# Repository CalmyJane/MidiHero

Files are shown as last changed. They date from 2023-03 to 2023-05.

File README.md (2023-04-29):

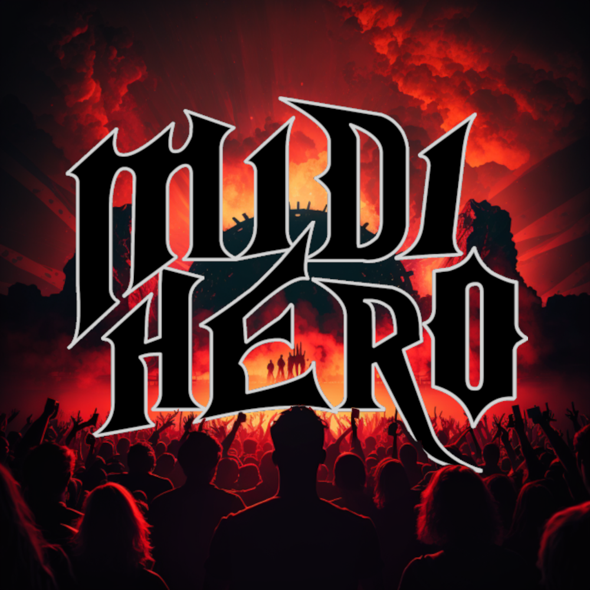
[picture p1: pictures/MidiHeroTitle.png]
Epic midi hero AI background intro image.


# 🎸 MidiHero
Transform your GuitarHero controller into a rockin' 5-pin MIDI controller for synths, man!
Btw, this readme was written by chatGPT in a "cool and authentic musician-to-musician-style" - enjoy!

## 🎶 Overview
This groovy repo provides the Arduino code and docs you need to turn a 5-button, PS3 GuitarHero controller into a rad MIDI controller. The modded axe sends MIDI notes through a 5-pin MIDI output, making it jam with any standard synth.

## 🤘 Usage Instructions
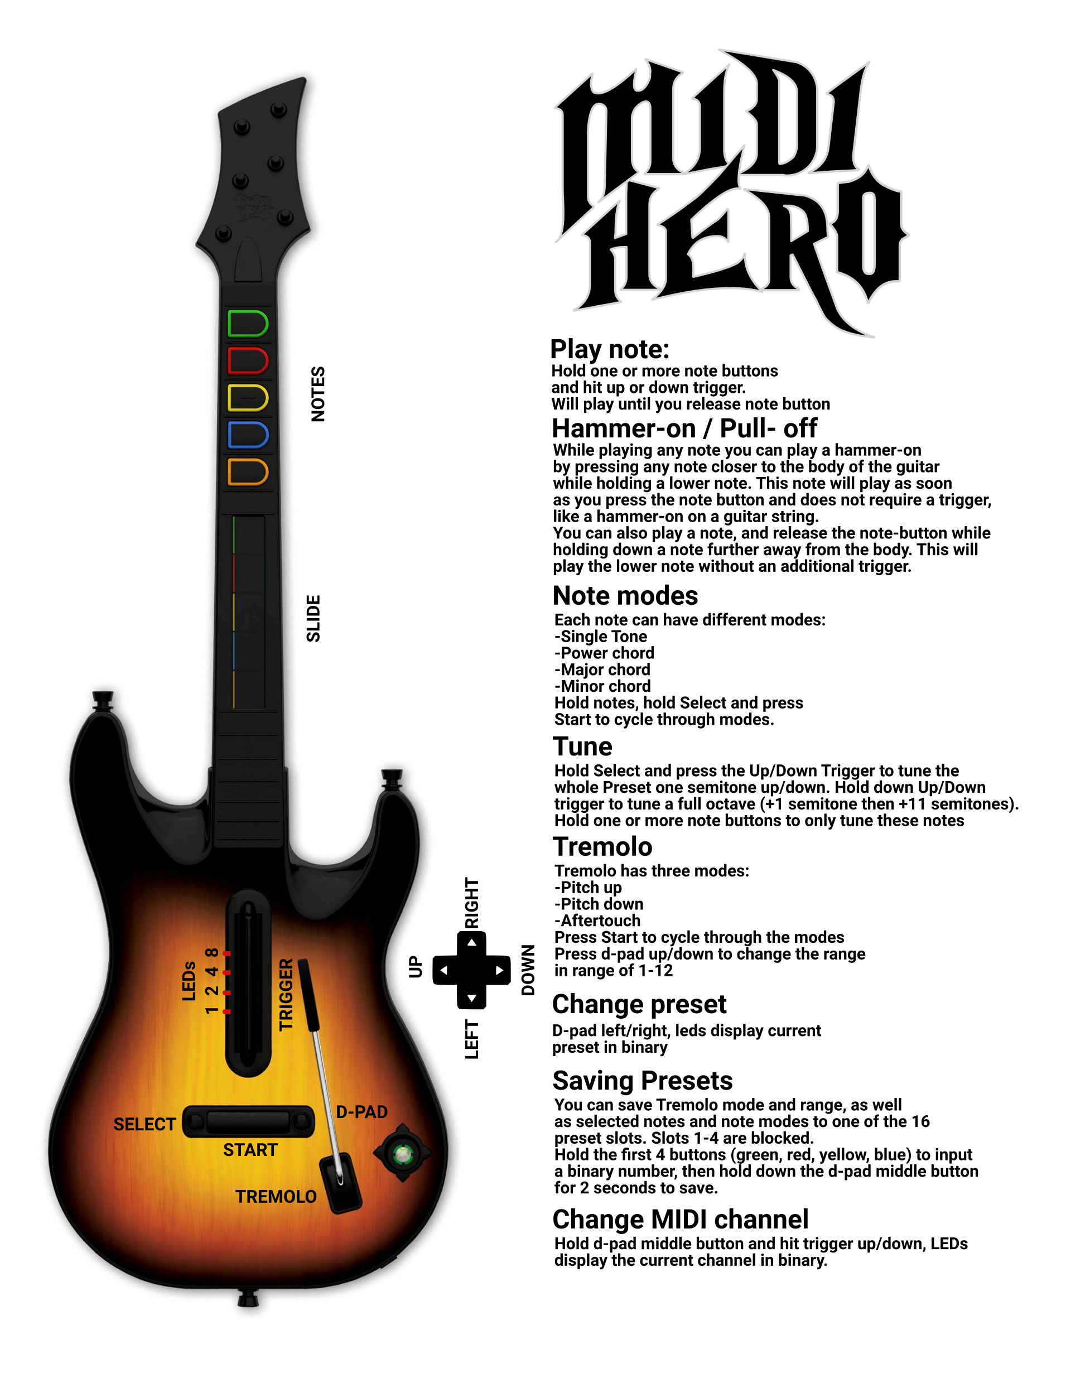
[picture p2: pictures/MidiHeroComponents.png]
Overview of the Midi Hero Guitar and it's Controls.


### Playing Notes
To shred a note, press and hold one or more `note` buttons and hit that up/down `trigger`. The note will sustain as long as you hold the `note` button, just like a real guitar, bro! Strum the `trigger` in both directions to play some wicked fast licks.

### Hammer-On / Pull-Off
While playing any note you can play a hammer-on by pressing any note closer to the body of the guitar while holding a lower note. This note will play as soon as you press the note button and does not require a trigger. You can also play a note, and release the note-button while holding down a note further away from the body. This will play the lower note without an additional trigger.

You can enable/disable hammeron functionality for any preset by holding `Select` and pressing `Start`.

### Preset Selection
Your guitar comes preloaded with 16 presets. A preset contains the currently selected notes and their modes, the current tremolo mode and tremolo range and a hammeron-flag. The LEDs indicate which is selected in binary. Press `d-pad left/right` to change the currently selected preset. Changes you make to a preset will remain until you reboot the guitar, unless you save your preset to permanently keep it on the instrument.

### Tremolo Functionality
Rock that `tremolo`! By default, it'll bend your pitch down by one semitone at full extension. You can adjust the bend range from 1 to 12 semitones! To change the range, press the `D-pad up/down`. Navigate the modes and watch for a flash of all `LEDs` to know you've made the switch. If no flash, you've hit the end of the range (1 or 12) - just navigate the other way, man!

Tremolo modes include:
* **Pitch Down** - Pitch bends down all notes by 1..12 semitones
* **Pitch Up** - Pitch bends up all notes by 1..12 semitones
* **Aftertouch** - Sends aftertouch (velocity) messages to modify current notes. With a synth like the Arturia MicroFreak, you can control anything through the modulation matrix - let your creativity flow!

You can change mode for your current preset by pressing `Start`.

### Guitar Tuning
Wanna tweak your presets? No problem, dude! Select a preset, then press and hold the `notes` you want to change. Adjust the pitch with `Shift + trigger up/down` for a semitone up or down. Transpose an entire preset by holding all notes and pressing `Shift + trigger up/down`. Just remember, custom presets won't be saved when you restart the guitar - they'll go back to default if not saved. But hey, it's a great way to reset if things get to funky!
You can also hold the up/down trigger while tuning to jump a full octave.

### Note Modes
Each note can have different modes:
* **Single Tone**
* **Power chord**
* **Major chord**
* **Minor chord**
Hold the notes you want to change, hold Select and press Start to cycle through their modes.

### MIDI Channel Selection
By default, your guitar sends notes on MIDI channel 1. We recommend setting your synth to accept all MIDI notes - check the settings! But if you need a specific channel, press the `D-pad` down and use the `up/down trigger` to change the channel. The active channel is shown in binary with flashing LEDs, from Channel 1 (1000) to Channel 15 (1111), and Channel 16 (0000). The channel is stored when device is powered off.

### Saving Presets
You can save Tremolo mode and range, as well as selected notes and note modes to one of the 16 preset slots. Hold the first 4 buttons (green, red, yellow, blue) to input a binary number, then hold the d-pad middle button to save. LEDs will blink when saved and go back to displaying the preset. Slots 1-4 are blocked and cannot be overwritten.

## Schematics

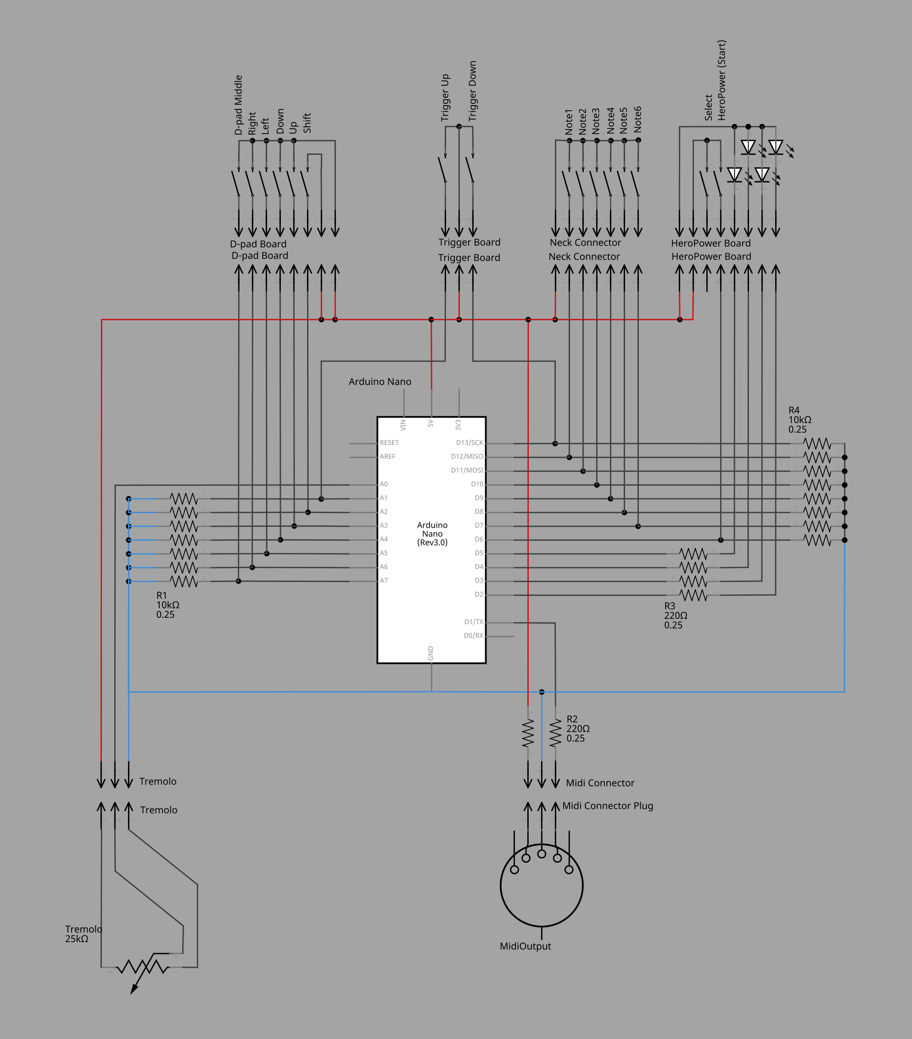
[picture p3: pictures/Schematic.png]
Schematic of the arduino and its IOs


## Internals
Inside view of the modded guitar controller
Inside the controller there is mostly Buttons that are placed on different boards. The neck is detachable and only contains the 6 `note` buttons and no additional circuitry, so it does not need to be opened or modified. Besides the buttons there is a potentiometer for the `tremolo`. Everything is attached to a controller through many flat ribbon cables. The controller is a bluetooth controller and could be used to turn something else into a guitarhero controller, maybe playing guitarhero with fruits? ;)

Inside the main frame there are 4 boards that contain several buttons. The boards usually have a GND-pin and several pins that can be connected to GND by pressing a button. To read the buttons with an arduino 5V is supplied to GND (don't get confused) of the board. The resulting signal is then read through a digital input pin with another grounding resistor. The circuit is as described in this tutorial:

https://docs.arduino.cc/built-in-examples/digital/Button

Details about the different boards inside the controller:
See the pictures folder for images of other controllers.

### Neck Connector
Some pins are not used in my version of the controller, maybe there are other controllers with an additional uController inside the neck, for now only the button-pins are used.

Front view of Neck Connector BoardBack view of Neck Connector Board

Pinout:
* 1 - Vcc - not connected
* 2 - SWDCLK - not connected
* 3 - RST/SWDIO - not connected
* 4 - MODE - not connected
* 5 - W1 - note 1
* 6 - W2 - note 2
* 7 - W3 - note 3
* 8 - B1 - note 1
* 9 - B2 - note 2
* 10- B3 - note 3
* 11- GND

### Trigger Board

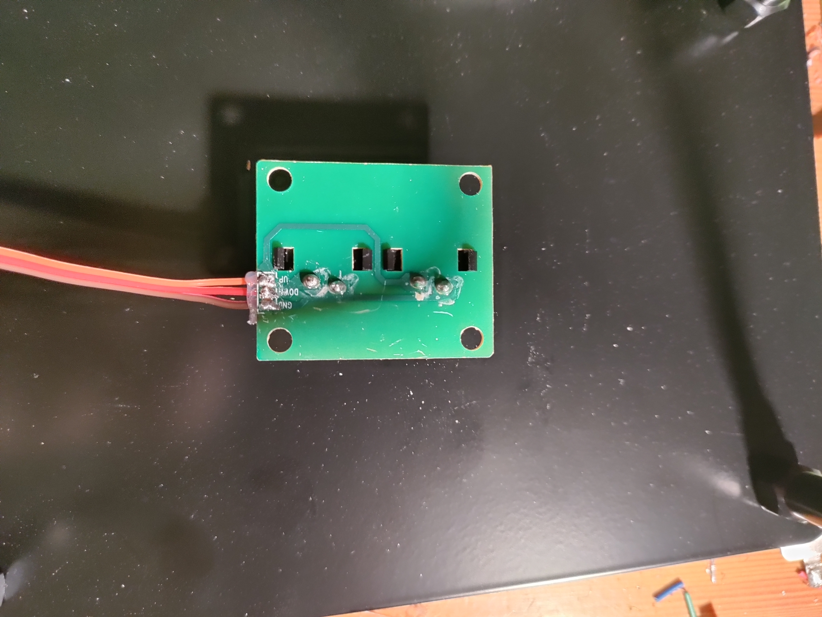
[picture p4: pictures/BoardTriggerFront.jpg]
Front view of Trigger Board
Back view of Trigger Board

Pinout:
* 1 - GND
* 2 - DOWN
* 3 - UP

### HeroPower Board
Start is the signal for the big HeroPower button, select is the two small buttons beside it. The buttons cannot be read seperately and they are not used for this mod. The board also contains 4 leds that are supplied through Vcc. They can be directly connected to the arduino (sinking their current into a digital output pin) through a 220 Ohn Resistor.

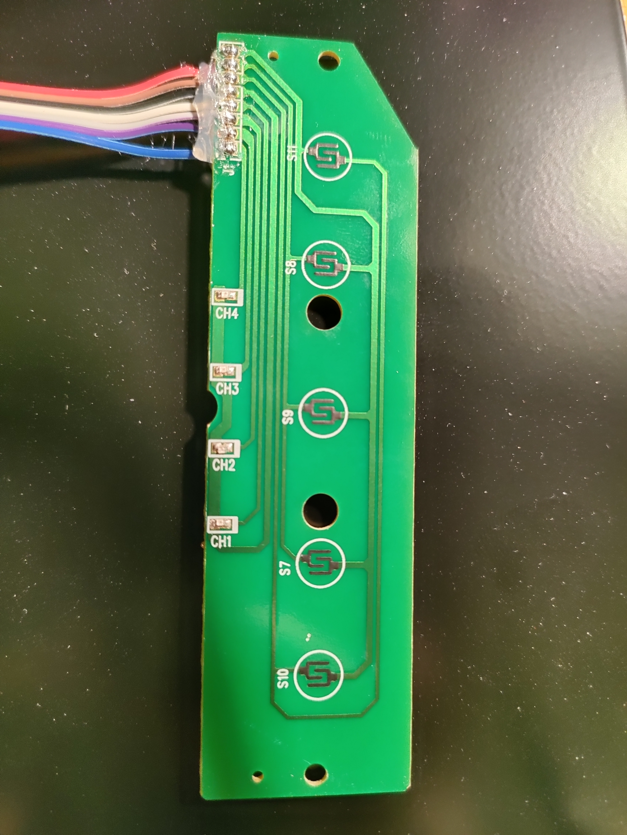
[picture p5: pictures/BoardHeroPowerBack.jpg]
Back view of Hero Power Board
Front view of Hero Power Board

Pinout:
* 1 - CH4 - LED4
* 2 - CH3 - LED3
* 3 - CH2 - LED2
* 4 - CH1 - LED1
* 5 - Vcc - +5V
* 6 - Start
* 7 - Select
* 8 - GND

### Navigation Board
The navigation board contains the `shift` button and the d-pad, the d-pad consists of 5 buttons, one for each direction and a center one that activates when pressing the middle of the dpad or pressing down the entire d-pad. This middle button can also activate randomly while nagvigating in some directions, so I recommend only using it to detect a complete push down of the d-pad by reading the middle button, and all directions at once.

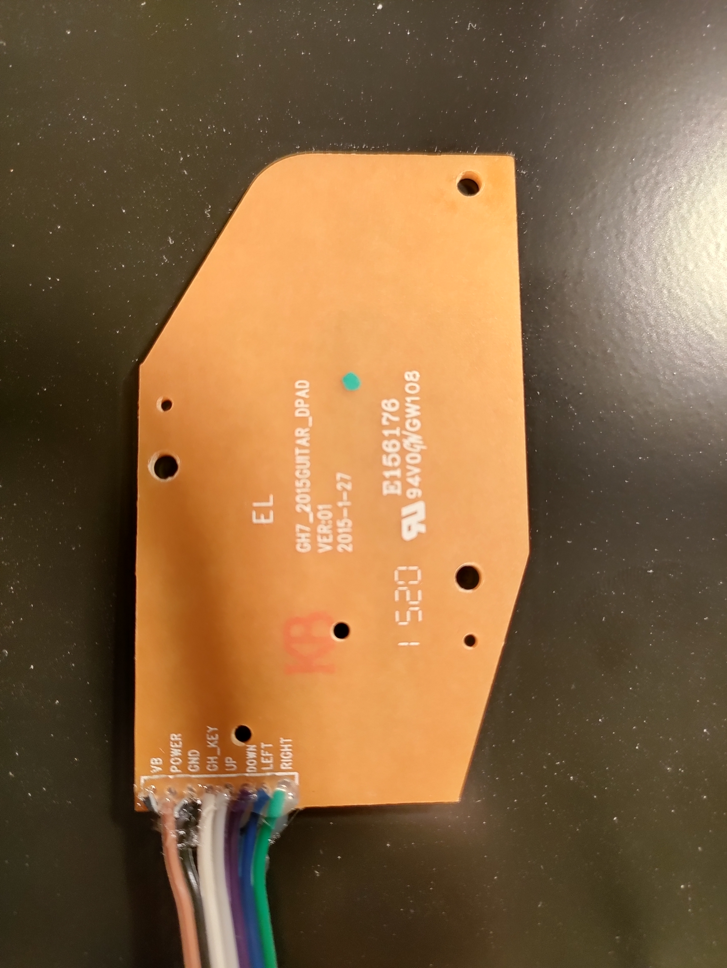
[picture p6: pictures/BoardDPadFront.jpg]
Front view of DPad Board
Back view of DPad Board

Pinout:
* 1 - VB - Shift button
* 2 - POWER - seperate channel for shift button, also connect to +5V
* 3 - GND - also 5V+
* 4 - CH_KEY - d-pad middle button
* 5 - UP
* 6 - DOWN
* 7 - LEFT
* 8 - RIGHT

## The Controller
The code runs on a arduino nano and can be run through the arduino IDE.
custom pcb for the midi herocustom pcb filled with components
The board mostly features pull-down resistors for all in- and output pins as in the button input tutorial. The signals from the different buttons are then connected to the arduino directly next to it's input pins as seen here:
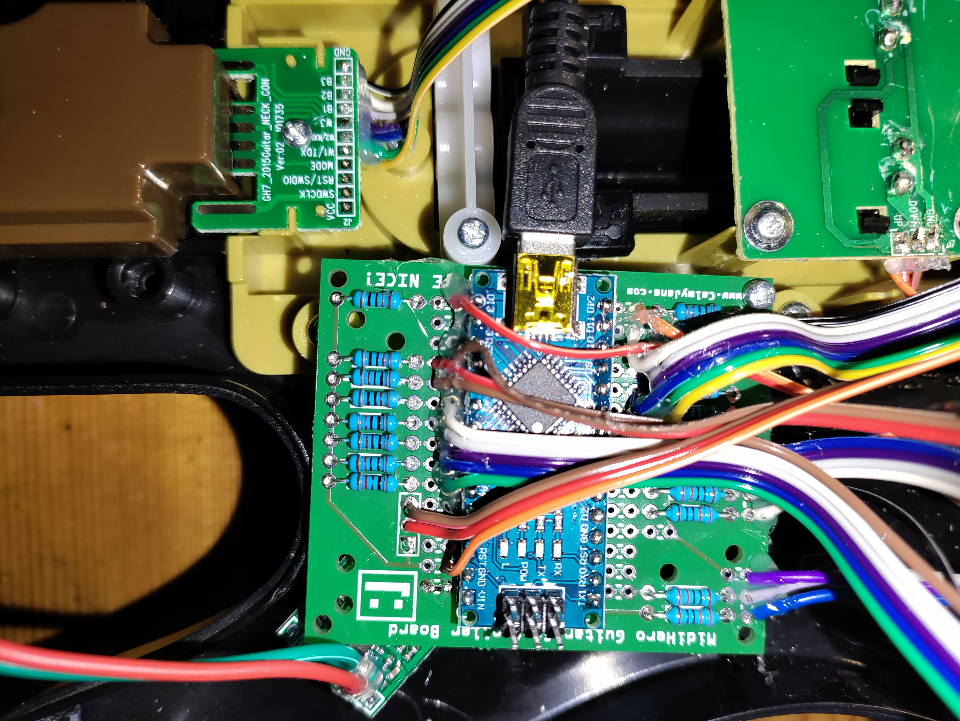
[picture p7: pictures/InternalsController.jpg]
Front view of the wired controller board


### Rx pin
The code uses all digital and analog pins except for Rx. You may be able to use it somehow, but I got a but with error messages when uploading new code while the button was connected to anything but ground, so I decided not to use it and keep the select buttons unwired.

### Power supply
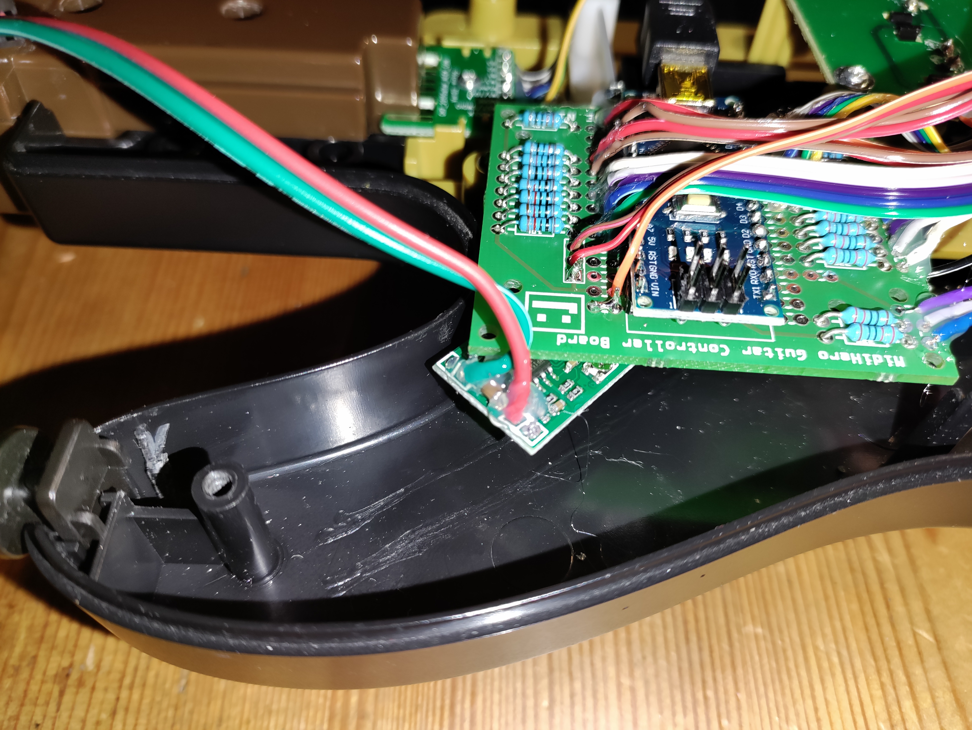
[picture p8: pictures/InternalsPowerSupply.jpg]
Detailed view of the power supply board


During debug the board is powered through USB via the USB port, in parallel there is a MP1584 buck converter wired to the Vin pin. The buck converter uses a 9V battery as power source and is adjusted to output +5V. So far it was fine having the usb-cable and the buck converter powering the board in parallel.

## Code
The code is split to two files for the 6 button PS3/PS4 version of the guitar and the 5 button PS3-Version. There are different models, but these two were most suitable, since both feature minimum 3 menu-buttons (dpad-middle, select and start) and 3 LEDs to indicate presets and other information.

My recommended model is the PS3 Guitar Hero World Tour Octane Red controller.

To run the code on your hardware, simply connect all wires from the different boards to your Arduinos IO pins. Important is only, that you use PWM-Pins for the LEDs (I use 6, 9, 10, 11). These are the only output pins. The other wires all connect to 5V, Gnd or any of the digital or analog input pins. I use A7 for the Tremolo potentiometer which is the only real analog input, the other wires are all digital.
You can connect them however it fits you and adjust the pin settings in the code in a dedicated section.

Once you have everything wired, I recommend to run the code and uncomment a debug-section that prints the different key-presses to the serial console. You can then look at the serial console and check if your key-mappings are correct. If not, adjust the input pins in the code.

Once this is done you can comment the section again and do a test with midi. Be aware that when printing to the serial console while having midi connected, the serial data will be send out through midi which usually leads to some pretty crazy sounds with your synthesizer. Very uncontrollable though.

The only adjustments you need to make is the pinouts, everything else should hopefully be ready to run.

## Tutorials

### Arduino Midi Player Tutorial
I took the Midi Output Circuit from this
https://docs.arduino.cc/built-in-examples/communication/Midi

### Arduino Button Input Tutorial
This is the circuit used for all buttons inside the guitar. Be aware, that the buttons in the controller do have a bit more resistance while on than usual buttons (up to 300 Ohms), so make sure you use 10k resistors to GND, smaller resistors may cause glitches.
https://docs.arduino.cc/built-in-examples/digital/Button

### Arduino Midi In- and Output
Same circuit as in the other tutorial, but also contains part for recieving midi which is a bit more complicated, but also doable. Also you don't necessarily need the Optocoupler circuit and can directly connect the data lines to your Rx pin, but decoupling is recommended of course.
https://www.instructables.com/Send-and-Receive-MIDI-with-Arduino/

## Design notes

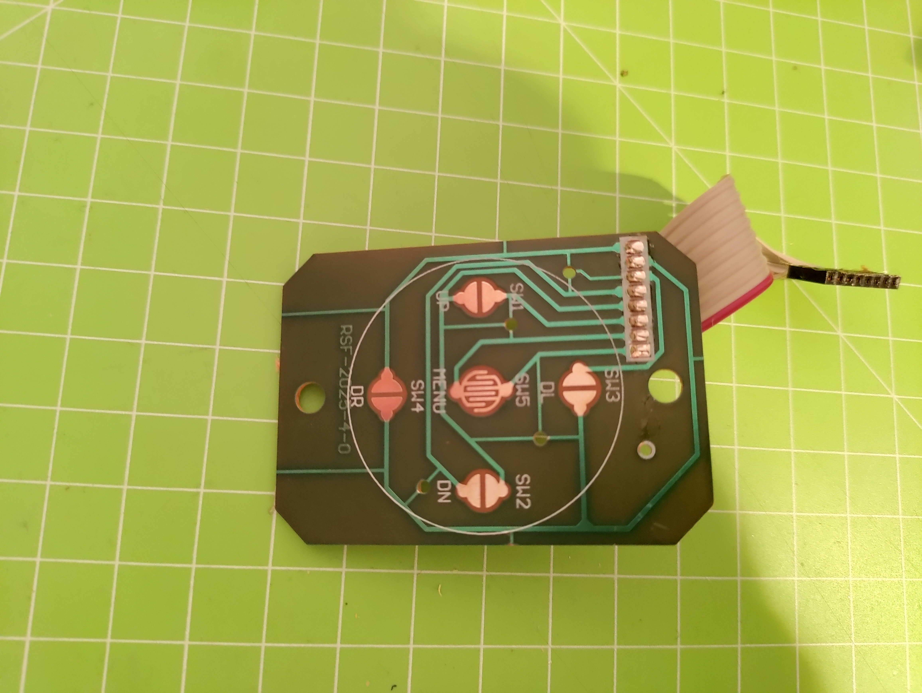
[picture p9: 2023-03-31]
pictures/BoardDPadBack5.jpg

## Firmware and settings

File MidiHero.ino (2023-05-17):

// ---- MIDI HERO FIRMWARE ----

// Project for ardution that reads several buttons, a potentiometer and a PWM-Signal (dutycycle) and converts them into MIDI-Messages
// uses Arduino nano to output MIDI messages on the Tx pin to a standart 5-pin-plug
// pwm dutycycle is read to get slider-value
// poti is read to get tremolo-value
// all other buttons on the guitar hero controller are read as digital inputs

// This code is written by Calmy Jane and based on various examples
//check out the readme for more information

#include <EEPROM.h>
#define buttonCount 5 //number of buttons on the guitar
#define presetCount 16

class MidiWriter{
  public:
    int channel = 0;
    MidiWriter(){
      Serial.begin(31250);
    }

    void write(int cmd, int data1, int data2){
      //writes 1-3 bytes
      int firstByte = cmd & 0xF0;
      if(firstByte != 0xF0){
      //if not system message, include midi channel information
        firstByte |= (channel & 0x0F);        
      }
      // Serial.print("write: ");
      // Serial.print(firstByte, HEX);
      // Serial.print(" - ");
      // Serial.print(data1, HEX);
      // Serial.print(" - ");
      // Serial.print(data2, HEX);
      // Serial.print(" \n");

      //write midi to tx pin
      Serial.write(firstByte);
      Serial.write(data1);
      Serial.write(data2);
    }

    void noteOnOff(int note, bool on){
      //0x90 = play note, 0x45 = medium velocity
      write(0x90, note, on?0x45:0x00); 
    }

    void pitchBend(int value) {   
      // Value is +/- 8192
        unsigned int change = 0x2000 + value;  //  0x2000 == No Change
        unsigned char low = change & 0x7F;  // Low 7 bits
        unsigned char high = (change >> 7) & 0x7F;  // High 7 bits
        write(0xE0, low, high);
    }
    
    void monoPressure(int noteValue, int value){
      //sends pressure message for monophonic aftertouch. there's also a message for polyphonic aftertoucht
      //value in 0..127
      //0xA0 = pressure message for aftertouch from 0..127
      // Serial.print("\n " + (String)value + " \n");
      write(0xA0, noteValue, value);
    }
    void changeMidiChannel(bool up){
      //Increments or Decrements the midiChannel with overroll on 0..16
      channel = ((((up?0x01:-0x01) + channel) % 0x10) + 0x10) % 0x10;
    }
};

class Note{
  private:
    int root = 0x3C;
    int mode = 0;
    // modes:
    // singleTone = 0,     // Note key plays a single tone
    // power = 1,    // Note key plays a power chord, tone, tone + 7 semitones, tone 1 octave
    // major = 2,    // Note key plays a major chord, tone, tone + 4 semitones, tone + 7 semitones
    // minor = 3     // Note key plays a minor chord, tone, tone + 3 semitones, tone + 7 semitones

  public:
    bool playing = false;
    Note(){
      //default constructor
    }

    Note(MidiWriter midi, int value, int noteMode){
      set(midi, value, noteMode);
    }

    void set(MidiWriter midi, int value, int noteMode){
      //set current note value 0xC3 = C4
      play(midi, false);
      root = value;
      mode = noteMode;
    }

    void setMode(int value){
      mode = value;
    }

    void play(MidiWriter midi, bool on){
      //send 0x90 command - play note - with 0x00 (note off) or 0x45 (not on) velocity
      if(playing || (!playing && on)){
        
      Serial.print(mode);
        switch(mode){
          case 0:
            //single note
            midi.noteOnOff(root, on);
            break;
          case 1:
            //power chord
            midi.noteOnOff(root + 7, on);
            midi.noteOnOff(root + 12, on);
            midi.noteOnOff(root, on);
            break;
          case 2:
            //major chord
            midi.noteOnOff(root + 4, on);
            midi.noteOnOff(root + 7, on);
            midi.noteOnOff(root, on);
            break;
          case 3:
            //minor chord
            midi.noteOnOff(root + 3, on);
            midi.noteOnOff(root + 7, on);
            midi.noteOnOff(root, on);
            break;
        }
        //do not send off when note is not playing, avoid "silent" messages
      }
      playing = on; //store current state
    }

    void tune(bool up, int semitones){
      // tune 1 semitone up/down
      root += up?semitones:-semitones;
    }

    int getRoot(){
      return root;
    }

    int changeMode(MidiWriter midi, bool up){
      play(midi, false);
      mode = (mode + (up?1:-1));
      if(mode >= 4){
        mode = 0;
      } else if (mode < 0){
        mode = 3;
      }
    }
};

class RollingAverage {
  public:
    RollingAverage(uint32_t n) {
      bufferSize = n;
      buffer = new uint32_t[bufferSize];
      bufferIndex = 0;
      bufferSum = 0;
      bufferCount = 0;
      // Initialize the buffer with zeros
      for (uint32_t i = 0; i < bufferSize; i++) {
        buffer[i] = 0;
      }
    }

    ~RollingAverage() {
      delete[] buffer;
    }

    void add(uint32_t amount) {
      bufferSum += amount;
      bufferSum -= buffer[bufferIndex];
      buffer[bufferIndex] = amount;
  
      bufferIndex = ((bufferIndex + 1) % bufferSize + bufferSize) % bufferSize; //positive modulo

      if (bufferCount < bufferSize) {
        bufferCount++;
      }
    }

    uint32_t get() {
      if (bufferCount == 0) {
        return 0;
      }
      return bufferSum / bufferCount;
    }

  private:
    uint32_t bufferSize;
    uint32_t *buffer;
    uint32_t bufferIndex;
    uint32_t bufferSum;
    uint32_t bufferCount;
};

class Button{
  public:
    bool state = false;
    bool lastState = false;
    bool pressed = false;
    bool released = false;
    int pin = 0;
    bool analogPin = false;
    bool inverted = true;

    Button(){
      
    }

    Button(int pinNumber){
      //Initialize button input
      pin = pinNumber;
      analogPin = (pinNumber >= A0 && pinNumber <= A7); //is analog pin?
      pinMode(pinNumber, INPUT_PULLUP);
    }

    void update(){
      //call periodically
      lastState = state;
      bool tmpState = false;
      if(analogPin){
        tmpState = analogRead(pin) > 400;
      } else {
        tmpState = digitalRead(pin);
      }
      if(inverted){
        state = !tmpState;
      } else {
        state = tmpState;
      }
      pressed = !lastState && state; //was pressed in this iteration
      released = lastState && !state; //was released in this iteration
    }
};

class Led{
  private:
    int pin;
    int brightness = 2;
    int16_t brightCounter = 0;
    int16_t brightPeriod = 10;
    uint32_t blinkRate = 0;
    uint32_t blinkDuty = 0;
    int16_t blinkBrightness = 0;
    int16_t prevBrightness = 0;
    int16_t blinkCount = 0;
    int16_t blinkCounter = 0;
    int lastMlls;
    bool state;
    bool timerPwm = false; //if a pwm-pin is used, use the pwm feature to get better resolution

    int invertBrightness(int brightness){
      return 255 - brightness;
    }

  public:
    bool inverted = false; //Set to true, depending on how you connected the LED
    Led(){
      
    }

    Led(int pin){
      //
      lastMlls = millis();
      this->pin = pin;
      pinMode(pin, OUTPUT);
      brightCounter = brightPeriod;
      switch(pin){
        case 3:
        case 5:
        case 6:
        case 9:
        case 10:
        case 11:
          //is PWM-Pin - use timer-pwm
          timerPwm = true;
        break;
        default:
          //not pwm-pin, use software timed pwm
          timerPwm = false;
        break;
      }
      setPin(false);
    }

    void update(){
      int mls = millis();
      int deltat = mls - lastMlls;
      lastMlls = mls;
      bool dimmed = false;
      //Dimming of the LED
      if(brightCounter > 0){
        brightCounter -= deltat;
        if(brightCounter < invertBrightness(brightness)/26){
          dimmed = false;
        } else {
          dimmed = true;
        }
        if(brightCounter <= 0){
          brightCounter = brightPeriod;
        }
      }
      //Blinking of the LED
      if(blinkCounter > 0 && blinkCount > 0){
        //blinking
        blinkCounter -= deltat;
        setPin(blinkCounter > (blinkRate - blinkDuty));
        if(blinkCounter <= 0){
          if(blinkCount != 0){
            if(blinkCount > 0){
              blinkCount--;
            }
            blinkCounter = blinkRate;
          } else {
            //blinkCount is 0 - blinking ended
            brightness = prevBrightness;
          }          
        }
      } else{
        //not blinking
        if(blinkCount != 0){
          //start another blink
          if(blinkCount > 0){
            //reduce if not blink forever
            blinkCount --;
          }
          blinkCounter = blinkRate;
          setPin(true);
        }
        setPin(state && (timerPwm || dimmed));
      }
    }

    void setPin(bool state){
      int onBright = timerPwm?brightness:255; //set brightness to 255 if not PWM-Pin, state will be toggled from update() to dim
      int offBright = 0;
      if(inverted){
        onBright = invertBrightness(onBright);
        offBright = 255;
      }
      analogWrite(pin, state?onBright:offBright);        
    }

    void setState(bool state){
      this->state = state;
      // setPin(state);
    }

    void blink(uint32_t rate, uint32_t duty, int count, int brightness){
      //sets to blink N times, count = -1 for infinite
      //rate in ms period time, 1000 slow rate, 10 fast rate
      //duty in 0..100 (%)
      blinkCount = 0;
      blinkCounter = 0;
      prevBrightness = this->brightness;
      setBrightness(brightness);
      blinkRate = rate;
      blinkDuty = (duty * rate)/100;
      blinkCount = count; //decrement, since first blink started
      blinkCounter = rate;
      setState(true);
    }

    void setBrightness(int brightness){
      //brightness in 0..10
      if(blinkCount > 0 && blinkCounter > 0){
        this->prevBrightness = brightness;
      } else {
        this->brightness = brightness;
      }
    }
};

class LedBar{
  //handles the 4 leds, blinks them, sets brightness through pwm
  private:
    int numericValue = 0; 
    Led leds[4];
  public:
    LedBar(){
      //empty default constructor
    }

    LedBar(int ledPins[4]){
      for(int i=0; i<4; i++){
        leds[i] = Led(ledPins[i]);
        leds[i].inverted = true;
      }
    }

    void update(){
      for(int i=0; i<4; i++){
        leds[i].update();
      }
    }

    void ShowBinary(int value){
      numericValue = value;
      bool bits[8];
      for (int i = 0; i < 4; i++) {
        bits[i] = ((value) >> (i)) & 0x01;
      }
      setLeds(bits);
    }

    void setLeds(bool values[4]){
      for(int i=0; i<4; i++){
        setLed(i, values[i]);
      }
    }

    void setLed(int led, bool value){
      leds[led].setState(value);
    }

    void setAll(bool on){
      bool lds[4] = {on,on,on,on};
      setLeds(lds);
    }

    void setBrightness(int value){
      //set Brightness from 0 to 4
      for(int i=0; i<4; i++){
        leds[i].setBrightness(value);
      }
    }

    void blink(uint32_t rate, uint32_t duty, int count){
      //blinks duration in ms all LEDs
      for(int i=0; i<4; i++){
        leds[i].setState(true);
        leds[i].blink(rate, duty, count, 100);
      }
    }

    void setValue(int value){
      //set the value to be displayed
      numericValue = value;
      ShowBinary(value);
    }
};

class Preset{
  public:
    Note notes[5];
    int tremoloMode = 0;
    int tremoloRange = 1;
    int tremoloModeCount = 3;
    bool hammeron = true; //will hammerons be played?
    Preset(){
      //empty default constructor
    }
    Preset(MidiWriter midi, int noteValues[5], int noteModes[5], int tremMode, int tremRange, bool hammeron){
      this->hammeron = hammeron;
      tremoloMode = tremMode;
      tremoloRange = tremRange;
      tremoloModeCount = 3;
      for(int i=0; i<5; i++){
        notes[i] = Note(midi, noteValues[i], noteModes[i]);
      }
    }

    void ChangeTremoloMode(bool up){
      //change tremoloMode
      tremoloMode += up?1:-1;
      if(tremoloMode < 0){
        tremoloMode = tremoloModeCount-1;
      }
      if(tremoloMode >= tremoloModeCount){
        tremoloMode = 0;
      }
    }
    
    bool ChangeTremoloRange(bool up){
      //change tremoloRange
      tremoloRange += up?1:-1;
      if(tremoloRange > 12){
        tremoloRange = 12;
      } else if(tremoloRange <= 0){
        tremoloRange = 1;
      } else {
        return true;
      }
      return false;
    }

    bool toggleHammeron(){
      hammeron = !hammeron;
      return hammeron;
    }
};
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
void loop() {
  int mls = millis();
  deltat = mls - lastMlls;
  lastMlls = mls;

  //read buttons and update current states
  btn_up.update();
  btn_down.update();
  btn_select.update();
  btn_start.update();
  btn_dup.update();
  btn_ddown.update();
  btn_dleft.update();
  btn_dright.update();
  btn_dmid.update();

  for(int i = 0; i<buttonCount; i++){
    btn_notes[i].update(); 
  }

  //read tremolo poti and send midi message on change
  tremolo.update(preset, midi, btn_notes);
  //read slide bar value
  readSlideBar();

  if(btn_select.pressed){
    // hero power button pressed
    if(btn_start.state){
      if(anyNote()){
        // tuning/ start pressed - change mode (single note, major chord, minor chord ..) for all active notes
        for (int i=0; i<buttonCount; i++){
          if (btn_notes[i].state){
            preset.notes[i].changeMode(midi, true);
            if(tremolo.value <= 500){
              preset.notes[i].play(midi, true);
            }
            leds.blink(LONG_BLINK, 50, 1);
          }
        }        
      } else{
        //change hammeron/pulloff enables
        preset.toggleHammeron();
      }

    } else {
      //change tremolo mode
      tremolo.reset(preset, midi, btn_notes);
      preset.ChangeTremoloMode(true); 
      leds.blink(SHORT_BLINK, 50, 1);
    }
  }

  //Trigger pressed
  if(btn_up.pressed || btn_down.pressed){
    if(btn_dmid.state){
      //currently editing Midi Channel
      midi.changeMidiChannel(btn_up.state);
      leds.setValue(midi.channel);
    } else {
      if(btn_start.state){
        //Tune Notes up/down
        TuneNotes(btn_up.state, 1);
        timeCounter = 0;
        leds.blink(SHORT_BLINK, 50, 1);
      } else {
        //Normal strum, play notes
        PlayNotes();          
      }
    }
  }

  //Trigger hold
  if(btn_up.state || btn_down.state){
    if(btn_start.state && timeCounter < octaveTimeout){
      timeCounter += deltat;
      if(timeCounter >= octaveTimeout){
        TuneNotes(btn_up.state, 11);
        leds.blink(LONG_BLINK, 50, 1);
      }
    }
  }

  //Start Button released
  if(btn_start.released){
    for(int i=0; i<buttonCount; i++){
      preset.notes[i].play(midi, false);
    }
  }

  //check for Hammeron
  for(int i=0; i<buttonCount; i++){
    if(btn_notes[i].pressed){
      bool hammeron = false;
      for(int j=0; j<i; j++){
        hammeron = hammeron || preset.notes[j].playing;
      }
      for(int j=0; j<buttonCount-i; j++){
        hammeron = hammeron && !preset.notes[buttonCount-1-j].playing;
      }
      if(hammeron && preset.hammeron){
        for(int j=0; j<buttonCount; j++){
          preset.notes[j].play(midi, false);
        }
        preset.notes[i].play(midi, true);
      }
    }
  }

  //reset notes when note button is released
  for(int i = 0; i < buttonCount; i++){
    if(btn_notes[i].released){
      //Mute notes on released button and check for pulloff
      int pulloff = -1;
      for(int j = 0; j<i; j++){
        if(btn_notes[j].state && !preset.notes[j].playing && preset.notes[i].playing){
          pulloff = j;
        }
      }
      preset.notes[i].play(midi, false);
      if(pulloff >= 0 && preset.hammeron){
        for(int j = 0; j<buttonCount; j++){
          preset.notes[j].play(midi, j==pulloff);
        }
      }
    }
  }

  //read D-Pad LEFT
  if(btn_dleft.pressed){  
    ChangePreset(true);
  }

  //read D-Pad RIGHT
  if(btn_dright.pressed){
    ChangePreset(false);
  }

  //read dpad UP
  if(btn_dup.pressed){
    //dpad up pressed - change preset
    if(preset.ChangeTremoloRange(true)){
      leds.blink(SHORT_BLINK, 50, 1);
    };
    tremolo.reset(preset, midi, btn_notes);
  }

  //read D-Pad DOWN
  if(btn_ddown.pressed){
    //cross down pressed
    if(preset.ChangeTremoloRange(false)){
      leds.blink(SHORT_BLINK, 50, 1);
    }; 
    tremolo.reset(preset, midi, btn_notes);
  }

  //read middle button of dpad pressed
  if(btn_dmid.pressed){
    previousMidiCh = midi.channel;
    if(anyNote()){
      //Start saving preset, start timeout
      timeCounter = 0;
      leds.setValue(15);
      leds.setBrightness(BRIGHT_DEFAULT);
    } else {
      //Change midi channel
      leds.setBrightness(BRIGHT_BRIGHT);  
      timeCounter = saveTimeout; //to prevent from first pressing menu and then pressing note buttons, notes should be pressed first
    }

  }

  //read middle button hold
  leds.setValue(currPreset);
  leds.setBrightness(BRIGHT_BRIGHT);
  if(btn_dmid.state){
    if(anyNote() && timeCounter < saveTimeout){
      leds.setValue(15);
      timeCounter += deltat;
      if(timeCounter >= saveTimeout){
        //timeout passed, save preset
        int sel = getNoteBinaryInput();
        cfg.updatePreset(sel, preset);
        presets[sel] = preset;
        leds.blink(VERY_LONG_BLINK, 50, 1);
      }
    } else if (!anyNote()){
      leds.setValue(midi.channel);
    }
  }

  //read middle button released
  if(btn_dmid.released){
    if(midi.channel != previousMidiCh){
      // WRITING TO EEPROM
      // writing midi channel to permanent memory if changed
      cfg.writeMidiCh(midi.channel);
      leds.blink(VERY_LONG_BLINK, 50, 1);
    }
    leds.setBrightness(BRIGHT_DEFAULT);
  }

  leds.update();

  // // Debug Code to print all Input states
  // Serial.print("N1: " + (String)btn_notes[0].state + 
  //             " N2: " + (String)btn_notes[1].state + 
  //             " N3: " + (String)btn_notes[2].state + 
  //             " N4: " + (String)btn_notes[3].state + 
  //             " N5: " + (String)btn_notes[4].state + 
  //             " UP: " + (String)btn_up.state + 
  //             " DOWN: " + (String)btn_down.state + 
  //             " START: " + (String)btn_start.state + 
  //             " SELECT: " + (String)btn_select.state + 
  //             " DUP: " + (String)btn_dup.state + 
  //             " DDOWN: " + (String)btn_ddown.state + 
  //             " DLEFT: " + (String)btn_dleft.state + 
  //             " DRIGHT: " + (String)btn_dright.state + 
  //             " DMID: " + (String)btn_dmid.state + 
  //             " TREMOLO: " + (String)tremolo.value + "\n"
  //             // " Slide: " + (String)slide.value + "\n"
  //             );
}

int strobeCounter = 0;
bool strobeState = false;

void readSlideBar(){
  //read slide-bar TOBEDONE
  // lastStateSlide = stateSlide;
  // slideVal.add(analogRead(pinSlide));
  // stateSlide = slideVal.get();
  // int tolerance = 50;
  // int slideNote = 0;
  // if(abs(stateSlide - 140) <= tolerance){
  //   slideNote = 1;
  // } else if(abs(stateSlide - 350) <= tolerance){
  //   slideNote = 2;
  // } else if(abs(stateSlide - 600) <= tolerance){
  //   slideNote = 3;
  // } else if(abs(stateSlide - 770) <= tolerance){
  //   slideNote = 4;
  // } else if(abs(stateSlide - 1000) <= tolerance){
  //   slideNote = 5;
  // } else if(abs(stateSlide - 500) <= tolerance){
  //   slideNote = 6;
  // }  
  // Serial.print("SlideVal: ");
  // Serial.print(slideNote);
  // Serial.print("\n");
}

bool anyNote(){
  //returns if any note button is pressed
  bool any = false;
  for(int i=0; i<buttonCount; i++){
    if(btn_notes[i].state){
      any = true;
    };
  }
  return any;
}

int getNoteBinaryInput(){
  //returns the first 4 buttons binary values as integer
  return (btn_notes[0].state << 3) | (btn_notes[1].state << 2) | (btn_notes[2].state << 1) | btn_notes[3].state;
}

void PlayNotes(){
  //Plays the notes of the currently pressed note buttons
  for(int i = 0; i < buttonCount; i++){
    if(btn_notes[i].state){
      preset.notes[i].play(midi, true);
      tremolo.update(preset, midi, btn_notes);
    }
  }
}

void TuneNotes(bool up, int semitones){
  //tunes the curently pressed note buttones one semitone up/down
  bool range = false;
  bool replay = tremolo.value <= 500; //don't replay if tremolo is pressed
  for(int i = 0; i < buttonCount; i++){
    //make sure, that no note exceeds 0x00..0x77
    range = (((preset.notes[i].getRoot() + semitones) >= 0x77) && up) || (((preset.notes[i].getRoot() - semitones) < 0x00) && !up) || range;
  }
  for(int i = 0; i < buttonCount; i++){
    if(btn_notes[i].state || !anyNote()){
      //Mute all notes
      preset.notes[i].play(midi, false);
      if(!range){
        preset.notes[i].tune(up, semitones); //increment or decrement
      }
      if(replay){
        //Play tuned notes
        preset.notes[i].play(midi, true);
      }
    }
  }
}
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

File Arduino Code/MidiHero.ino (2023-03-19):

/*
  MIDI note player

  This sketch shows how to use the serial transmit pin (pin 1) to send MIDI note data.
  If this circuit is connected to a MIDI synth, it will play the notes
  F#-0 (0x1E) to F#-5 (0x5A) in sequence.

  The circuit:
  - digital in 1 connected to MIDI jack pin 5
  - MIDI jack pin 2 connected to ground
  - MIDI jack pin 4 connected to +5V through 220 ohm resistor
  - Attach a MIDI cable to the jack, then to a MIDI synth, and play music.

  created 13 Jun 2006
  modified 13 Aug 2012
  by Tom Igoe

  This example code is in the public domain.

  https://www.arduino.cc/en/Tutorial/BuiltInExamples/Midi
*/
const int pinNotes[6] = {8,9,10,5,6,7};
const int pinLeds[4] = {12,4,3,2};

const int pinUp = 11;
const int pinDown = A7;
// const int pinStart = 13;
const int pinTremolo = A0;
const int pinSelect = A1;
const int pinDpadUp = A2;
const int pinDpadDown = A3;
const int pinDpadLeft = A4;
const int pinDpadRight = A5;
const int pinShift = A6;
const int pinDpadAll = 13;

const int presetCount = 4;
//4 presets of 6 notes each. May be edited later by user
int notes[presetCount][6] = {{0x3C, 0x3E, 0x40, 0x41, 0x43, 0x45}, // C4, D4, E4, F4, G4, A4 - c-major
                             {0x40, 0x43, 0x45, 0x46, 0x4A, 0x4C}, // E4, G4, A4, Bb4, D5, E5 - e-minor pentatonik
                             {0x3C, 0x3E, 0x40, 0x43, 0x45, 0x48}, // C4, D4, E4, G4, A4, C5 - c-major pentatonik
                             {0x3C, 0x3F, 0x43, 0x37, 0x3A, 0x3E}};// C3, D#4, G4, G3, Bb3, D4 - c minor and g minor chords
int currPreset = 0;
int lastPreset = 1;

int tremoloRange = 1; //the range of the pitchbend in semitones (-12 to 12, 0 is skipped)
const int tremoloModeCount = 3; //number of different bend modes
int tremoloMode = 0; //counter for current bend mode (0..bendModes)

int ledCounter = 0; //used to blink the leds
int lastMillis = 0; //used to calculate delta t

int midiChannel = 0x00; //stores the midichannel 0-15, 0 = all channels

bool stateNotes[6] = {0, 0, 0, 0, 0, 0};
bool stateUp = 0;
bool stateDown = 0;
// bool stateStart = 0;
int stateTremolo = 0; //amount of tremolo pressed, 1023 when released, 0 when pressed down
bool stateSelect = 0;
bool stateDpadUp = 0;
bool stateDpadDown = 0;
bool stateDpadLeft = 0;
bool stateDpadRight = 0;
bool stateShift = 0;
bool stateDpadAll = 0;

bool lastStateNotes[6] = {0,0,0,0,0,0};
bool lastStateUp = 0;
bool lastStateDown = 0;
// bool lastStateStart = 0;
int lastStateTremolo = 0;
bool lastStateSelect = 0;
bool lastStateDpadUp = 0;
bool lastStateDpadDown = 0;
bool lastStateDpadLeft = 0;
bool lastStateDpadRight = 0;
bool lastStateShift = 0;
bool lastStateDpadAll = 0;


void setup() {
  // Set MIDI baud rate:
  Serial.begin(31250);

  for(int i = 0; i <= 5; i++){
    pinMode(pinNotes[i], INPUT);
  }

  pinMode(pinUp, INPUT);
  pinMode(pinDown, INPUT);
  pinMode(pinTremolo, INPUT);
  pinMode(pinSelect, INPUT);
  pinMode(pinDpadUp, INPUT);
  pinMode(pinDpadDown, INPUT);
  pinMode(pinDpadLeft, INPUT);
  pinMode(pinDpadRight, INPUT);
  pinMode(pinShift, INPUT);
  pinMode(pinDpadAll, INPUT);

  pinMode(LED_BUILTIN, OUTPUT);
  for(int i = 0; i <= 3; i++){
    pinMode(pinLeds[i], OUTPUT);
  }
}

void loop() {
  // play notes from F#-0 (0x1E) to F#-5 (0x5A):
  // for (int note = 0x1E; note < 0x5A; note++) {
  //   //Note on channel 1 (0x90), some note value (note), middle velocity (0x45):
  //   noteOn(0x90, note, 0x45);
  //   delay(100);
  //   //Note on channel 1 (0x90), some note value (note), silent velocity (0x00):
  //   noteOn(0x90, note, 0x40);
  //   delay(100);
  // }

  for(int i = 0; i <= 5; i++){
    lastStateNotes[i] = stateNotes[i];
    stateNotes[i] = digitalRead(pinNotes[i]);
  }

  lastStateUp = stateUp;
  stateUp = digitalRead(pinUp) > 0;
  lastStateDown = stateDown;
  stateDown = analogRead(pinDown) > 100;
  // lastStateStart = stateStart;
  // stateStart = digitalRead(pinStart) > 0;
  lastStateTremolo = stateTremolo;
  stateTremolo = analogRead(pinTremolo);
  lastStateSelect = stateSelect;
  stateSelect = analogRead(pinSelect) > 100;
  lastStateDpadUp = stateDpadUp;
  stateDpadUp = analogRead(pinDpadUp) > 100;
  lastStateDpadDown = stateDpadDown;
  stateDpadDown = analogRead(pinDpadDown) > 100;
  lastStateDpadLeft = stateDpadLeft;
  stateDpadLeft = analogRead(pinDpadLeft) > 100;
  lastStateDpadRight = stateDpadRight;
  stateDpadRight = analogRead(pinDpadRight) > 100;
  lastStateShift = stateShift;
  stateShift = analogRead(pinShift) > 100;
  lastStateDpadAll = stateDpadAll;
  stateDpadAll = analogRead(pinDpadAll) > 100;

  if(stateSelect && !lastStateSelect){
    ChangePreset(true);
  }

  if(!lastStateUp && stateUp || (!lastStateDown && stateDown)){
    if(stateDpadAll && stateDpadLeft && stateDpadRight && stateDpadUp && stateDpadDown){
      //currently editing Midi Channel
      ChangeMidiChannel(stateUp);
    } else {
      if(stateShift){
        //Tune Notes up/down
        TuneNotes(stateUp);
      } else {
        //Normal strum, play notes
        PlayNotes();            
      }
    }
  }

  //reset notes when note button is released
  for(int i = 0; i <= 5; i++){
    if(!stateNotes[i] && lastStateNotes[i]){
      //Mute every released note
      PlayNote(notes[currPreset][i], false);
      UpdateTremolo();
    }
  }

  //read tremolo change
  if(abs(lastStateTremolo - stateTremolo) > 3){
      UpdateTremolo();
  }

  //read D-Pad LEFT
  if(stateDpadLeft && !lastStateDpadLeft){
    ChangeTremoloMode(true);    
  }

  //read D-Pad RIGHT
  if(stateDpadRight && !lastStateDpadRight){
    ChangeTremoloMode(false);
  }

  //read dpad UP
  if(!lastStateDpadUp && stateDpadUp){
    //dpad up pressed - change preset
    ChangeTremoloRange(true);
  }

  //read D-Pad DOWN
  if(!lastStateDpadDown && stateDpadDown){
    //cross down pressed
    ChangeTremoloRange(false);
  }

  //Read D-pad PRESSED to change Midi Channel
  if(stateDpadAll && stateDpadLeft && stateDpadRight && stateDpadUp && stateDpadDown){
    //cross pressed down completely
    bool bits[8];
    for (int i = 0; i < 4; i++) {
      bits[i] = ((midiChannel + 0x01) >> (i)) & 0x01;
    }
    UpdateStrobe(50, bits);
  }else{
    UpdateLed();    
  }
}

int strobeCounter = 0;
bool strobeState = false;

void PlayNotes(){
  //Plays the notes of the currently pressed note buttons
  for(int i = 0; i <= 5; i++){
    if(stateNotes[i] != 0){
      PlayNote(notes[currPreset][i], true);
      UpdateTremolo();
    }
  }
}

void TuneNotes(bool up){
  //tunes the curently pressed note buttones one semitone up/down
  for(int i = 0; i<=5; i++){
    if(stateNotes[i]){
      //Mute all notes
      PlayNote(notes[currPreset][i], false);
      notes[currPreset][i] += up?1:-1; //increment or decrement
      //Play tuned notes
      PlayNote(notes[currPreset][i], true);
    }
  }
}
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

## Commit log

2023-03-17 Added MidiHero.ino file for Arduino IDE. Changed input to store boolean values instead of integers to avoid unnecessary comparisons lateron.
    [MidiHero.ino]
2023-03-18 Added MidiChannel-Selection via push-down navigation cross and use up/down-trigger to select Channel. Channel will be displayed as binary on the LEDs from 1 (1000), 2 (0100) to 15 (1,1,1,1) and 16 (0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
2023-03-18 Changed button assignment to change tremoloRange with left/right instead of up/down on the dpad.
2023-03-18 Added Schematics
    [Schematic.fzz]
2023-03-19 Added PCB layout.
    [pcb.fzz]
2023-03-19 Refactored code a lot. Added new PCB in Fritzing
    [SmallSchematic.fzz]
2023-03-19 Cleaned up repository
    [Schematic.fzz, SmallSchematic.fzz, pcb.fzz]
2023-03-21 added infos about power supply to README.md
2023-03-26 Modified code to fit to new manufactured circuit board (changed pinout).
2023-03-26 Added detail view of neck connector to README.md
2023-03-26 shrinked images for neck connector
2023-03-28 Creating new branch for the 5-Button guitar version. The model I use has 5 note-buttons, a D-Pad with middle button, a HeroPower-Button and Start-Buttons, Up/Down Trigger, 4 LEDs and a slide-bar.
2023-03-29 Modified code a lot. Introduced classes MidiWriter and Note. Notes can now be a single note or a chord, the mode can be changed by holding shift/tune and press the heropower button. This will cycle t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
2023-03-29 Optimized code, added button and ledbar classes. Implemented different brightness and blinking modes for the leds.
2023-03-30 Added documentation for 5-button version and new features.
2023-03-31 Modified readme a bit. Added led flashes on save-operation.
2023-03-31 Made LEDs blink nicer.
2023-03-31 Added images for 5-button guitar to pictures folder
2023-04-11 Added mute functionality, holding down tremolo will not play notes when tuning or changing chord modes. Added some blinks and stuff. Found out, that I used the wrong pinout, I didnt connect the LEDs 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
    [SmallSchematic.fzz]
2023-04-20 fixed schematic.
    [SmallSchematic.fzz]
2023-04-27 Added 6 button version file, and refactored the main code a bit by addint a poti and tremolo class. Not fully working yet.
2023-04-28 Fixed Tremolo/Poti issue, now guitar works fine for 5 buttons.
    [MidiHero.ino]
2023-04-28 Fixed another small bug where notes won't replay when tremolo isnt pressed down. Saving to eeprom also works.
    [MidiHero.ino]
2023-04-28 Debugged code, added enable/disable for hammeron/pulloff for every preset. copied code to file for 6-button version, and fixed that one for the 6 button controller. Got 3 working controllers now.
    [6ButtonMidiHero.ino, MidiHero.ino]
2023-04-29 Added info on how to get started with your own board
2023-05-07 Added small PCB layout using the internal pullup resistors of the arduino ... took me way to long to find out :D Also changed pinout in code for a new guitar I built.
    [MidiHero.fzz]
2023-05-17 Modified code to use internal pullup for the buttons and to work with the new board. Sadly new board has an issue, I choose the wrong pins for the LEDs, D8 is not a PWM-pin. have to redesign that.
    [MidiHero.ino]
